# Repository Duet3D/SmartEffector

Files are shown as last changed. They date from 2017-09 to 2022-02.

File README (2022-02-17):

The Duet3d Smart Effector design files repository.

See https://www.duet3d.com/DeltaSmartEffector for more information and to purchase a smart effector.

Duet3d Delta Smart Effector
Design by Tony Lock and David Crocker
LICENSE: see the LICENSE file in the repository
Documentation: https://docs.duet3d.com/Duet3D_hardware/Accessories/Smart_Effector
Discussion: https://www.duet3d.com/forum/

Developed in KiCAD: http://www.kicad-pcb.org/display/KICAD/KiCad+EDA+Software+Suite

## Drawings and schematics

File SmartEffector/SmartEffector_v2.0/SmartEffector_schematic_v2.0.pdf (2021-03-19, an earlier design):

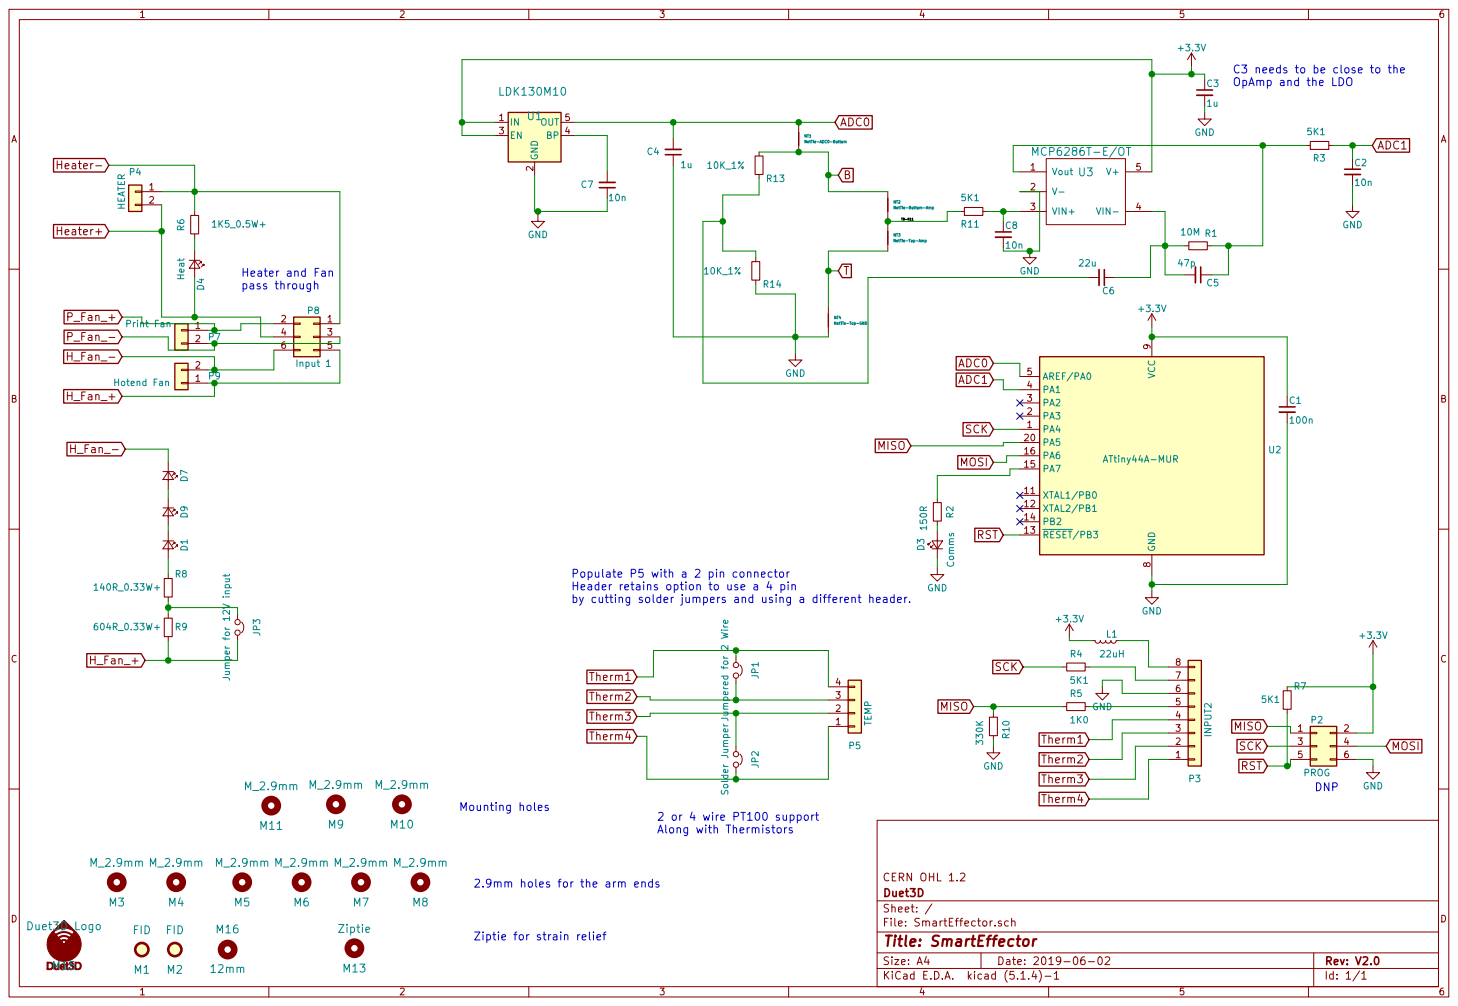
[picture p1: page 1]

C3 needs to be close to the
OpAmp and the LDO

NT3 NetTie-Top-Amp NT2NetTie-Bottom-Amp NT1NetTie-ADC0-Bottom

Populate P5 with a 2 pin connector
Header retains option to use a 4 pin
by cutting solder jumpers and using a different header.

CERN OHL 1.2
Id: 1/1 Title: SmartEffector File: SmartEffector.sch Sheet: / Duet3D

Ziptie for strain relief 2.9mm holes for the arm ends

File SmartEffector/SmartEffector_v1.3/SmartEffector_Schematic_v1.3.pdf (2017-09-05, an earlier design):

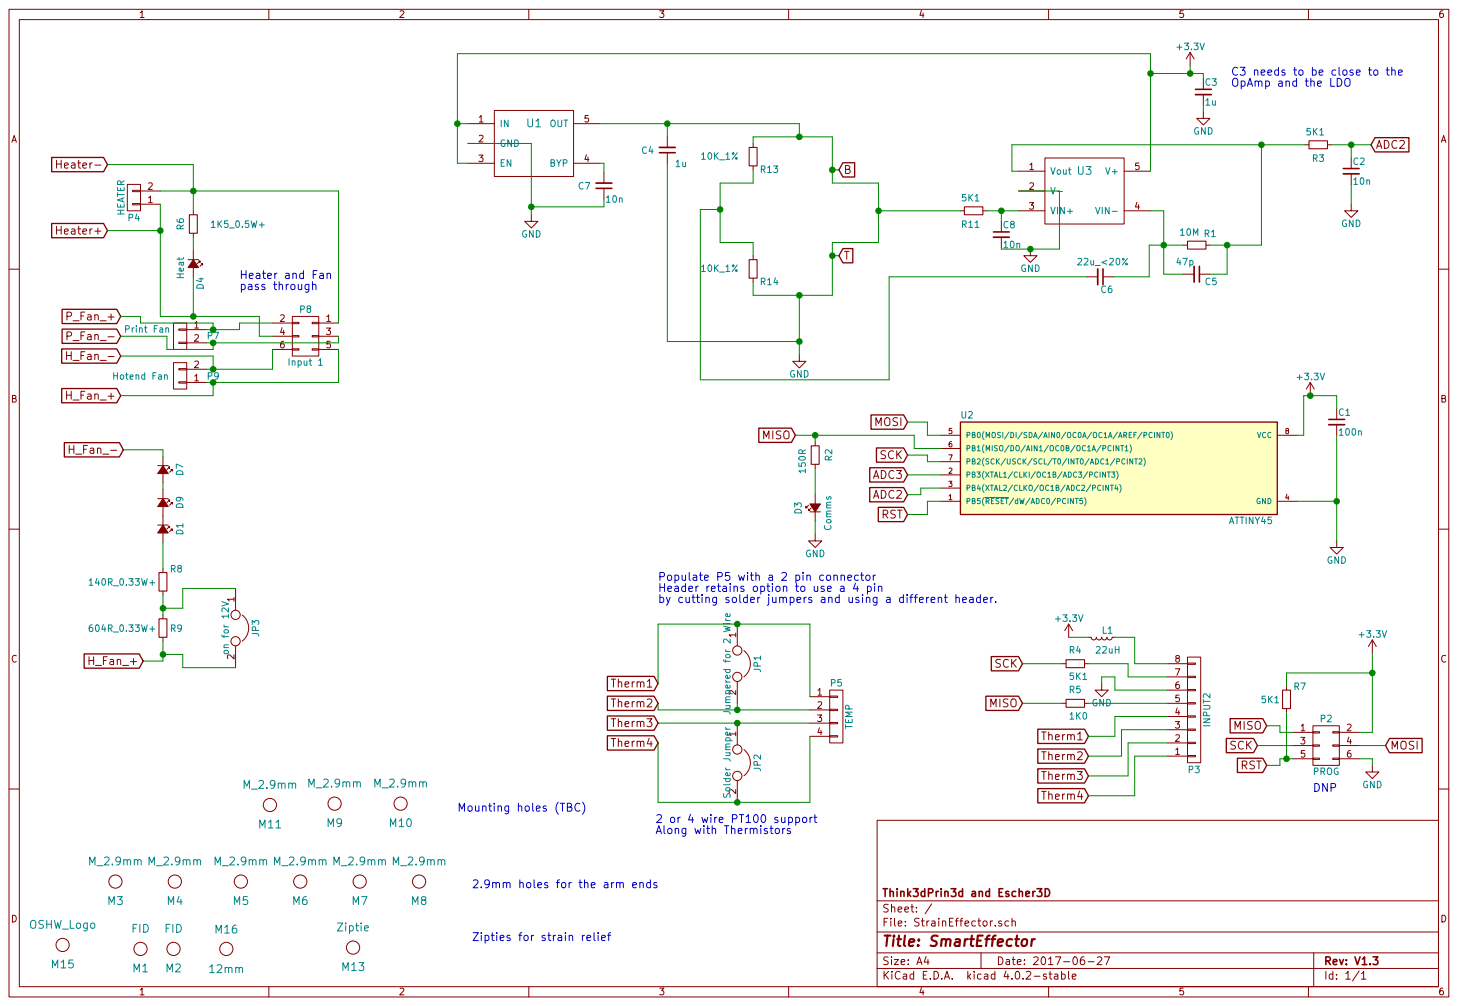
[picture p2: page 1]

1 2 JP3 on for 12V Heater+ Heater- C3

OpAmp and the LDO

1 2 JP2 Solder Jumper 1 2 JP1 Jumpered for 2 Wire C8

Populate P5 with a 2 pin connector
Header retains option to use a 4 pin

by cutting solder jumpers and using a different header. Therm4 Therm3

Id: 1/1 Title: SmartEffector File: StrainEffector.sch Sheet: / Think3dPrin3d and Escher3D

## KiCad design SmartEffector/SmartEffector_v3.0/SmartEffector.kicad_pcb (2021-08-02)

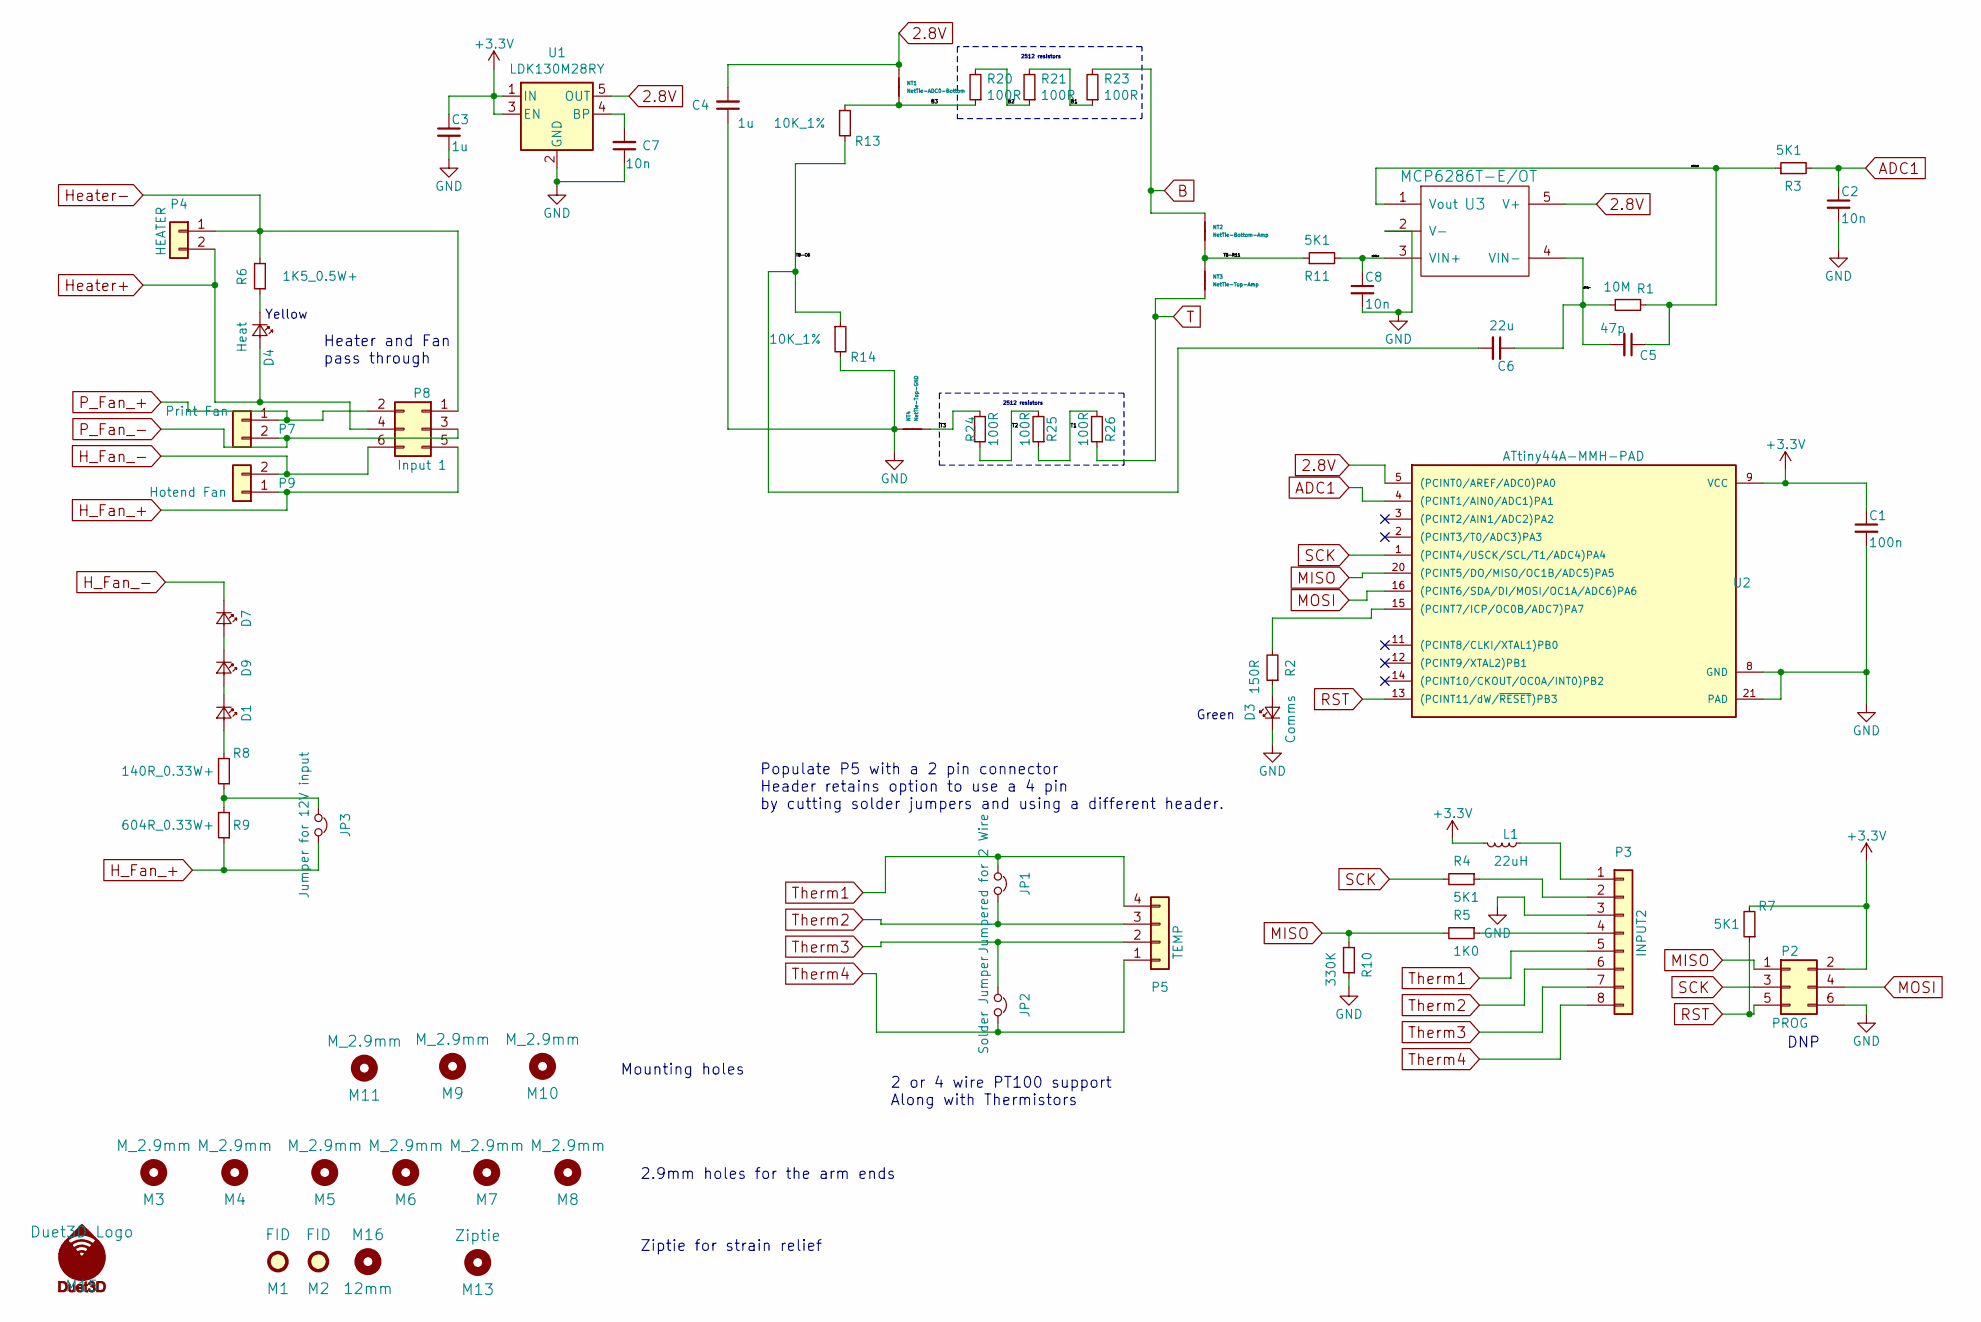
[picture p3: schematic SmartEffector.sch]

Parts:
C1: 100n; C_0402_1005Metric_Wbry; Part Number CL05A104KA5NNNC
C2, C7, C8: 10n; C_0402_1005Metric_Wbry; Part Number CL05B103KB5NNNC
C3, C4: 1u; C_0603_1608Metric_Wbry; Part Number CL10B105MO8NNWC
C5: 47p; C_0603_1608Metric_Wbry; Part Number 06035C470JAT2A
C6: 22u; C_0805_2012Metric; Part Number GRM21BR61A226ME51L or similar
D1, D7, D9: illum; LED_Wurth-158302260; Part Number 158302260
D3: Comms; LED_1206_bottom_entry_156120VS75000; Part Number 156120VS75000
D4: Heat; LED_1206_bottom_entry_156120VS75000; Part Number 156120YS75000
JP1: Jumpered for 2 Wire; SJ_Bridged; Part Number Virtual component DNP
JP2: Solder Jumper; SJ_Bridged; Part Number Virtual component DNP
JP3: Jumper for 12V input; JUMPER
L1: 22uH; L_0805_2012Metric; Part Number MLZ2012M220WT000
M1, M2: FID; Fiducial_1mm_Dia_2.54mm_Outer_CopperTop; Part Number Virtual component DNP
M3, M4, M5, M6, M7, M8, M9, M10, M11: M_2.9mm; MountingHole_2.9mm; Part Number Virtual component DNP
M13: Ziptie; Ziptie_small; Part Number Virtual component DNP
M15: Duet3D Logo; LOGO_Duet3d_CU_Mask; Part Number Virtual component DNP
M16: 12mm; 12mmHole; Part Number Virtual component DNP
NT1: NetTie-ADC0-Bottom; NetTie-2_SMD_Pad0.25mm; Part Number Virtual component DNP
NT2: NetTie-Bottom-Amp; NetTie-2_SMD_Pad0.5mm; Part Number Virtual component DNP
NT3: NetTie-Top-Amp; NetTie-2_SMD_Pad0.5mm; Part Number Virtual component DNP
NT4: NetTie-Top-GND; NetTie-2_SMD_Pad0.5mm; Part Number Virtual component DNP
P2: PROG; Test_Point_2x3; Part Number Virtual component DNP
P3: INPUT2; Molex_KK-254_AE-6410-08A_1x08_P2.54mm_Vertical
P4: HEATER; 3.5MM_2X1
P5: TEMP; Microfit_01x02or04_43650-0227
P7: Print Fan; Wurth_61900211121-1x02_P2.54mm_Vertical-(Molex_KK-254_AE-64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
P8: Input 1; Microfit_02x03
P9: Hotend Fan; Microfit_01x02_43650-0227
R1: 10M; R_0603_1608Metric_Wbry; Part Number RMCF0603JG10M0
R2: 150R; R_0402_1005Metric_Wbry; Part Number RC0402FR-07150RL
R3, R4, R7, R11: 5K1; R_0402_1005Metric_Wbry; Part Number RMCF0402FT5K10
R5: 1K0; R_0402_1005Metric_Wbry; Part Number CR0402-FX-1001GLF
R6: 1K5_0.5W+; R_1206; Part Number CRGH1206F1K5
R8: 140R_0.33W+; R_0805_extended_pads; Part Number ERJP06F1400V
R9: 604R_0.33W+; R_1206_3216Metric; Part Number RNCP1206FTD604R
R10: 330K; R_0402_1005Metric_Wbry; Part Number RMCF0402FT330K
R13, R14: 10K_1%; R_0402_1005Metric_Wbry; Part Number RK73H1ETTP1002F
R20, R21, R23, R24, R25, R26: 100R; R_2512_6332Metric; Part Number CRCW2512100RFKEG
U1: LDK130M28RY; SOT-23-5L; Part Number LDK130M28RY with LDK130M29R as an alter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
U2: ATtiny44A-MMH-PAD; QFN-20-1EP_4x4mm_Pitch0.5mm; Part Number ATtiny44A-MUR
U3: MCP6286T-E/OT; SOT-23-5L; Part Number OPA377AIDBVR preferred, possible to rev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

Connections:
2.8V: C4.2, NT1.1, U1.5 (OUT), U2.5 ((PCINT0/AREF/ADC0)PA0), U3.5 (V+)
+3V3: C1.1, C3.1, L1.2, P2.2, R7.2, U1.1 (IN), U1.3 (EN), U2.9 (VCC)
/B1: R21.2, R23.1
/B2: R20.2, R21.1
/B3: NT1.2, R13.1, R20.1
/T1: R25.1, R26.2
/T2: R24.2, R25.2
/T3: NT4.2, R24.1
/TB-C6: C6.2, R13.2, R14.1
/TB-R11: NT2.2, NT3.1, R11.1
/u3Vout: C5.1, R1.2, R3.1, U3.1 (Vout)
/u3vin+: C8.1, R11.2, U3.3 (VIN+)
/u3vin-: C5.2, C6.1, R1.1, U3.4 (VIN-)
ADC1: C2.1, R3.2, U2.4 ((PCINT1/AIN0/ADC1)PA1)
B: NT2.1, R23.2
GND: C1.2, C2.2, C3.2, C4.1, C7.1, C8.2, D3.1 (K), NT4.1, P2.6, P3.3, R10.1, R14.2, U1.2 (GND), U2.8 (GND), U2.21 (PAD), U3.2 (V-)
H_Fan_+: JP3.2, P8.5, P9.1, R9.1
H_Fan_-: D7.1 (K), P8.6, P9.2
Heater+: D4.2 (A), P4.2, P8.4
Heater-: P4.1, P8.1, R6.2
MISO: P2.1, R5.2, R10.2, U2.20 ((PCINT5/DO/MISO/OC1B/ADC5)PA5)
MOSI: P2.4, U2.16 ((PCINT6/SDA/DI/MOSI/OC1A/ADC6)PA6)
unnamed: C7.2, U1.4 (BP)
unnamed: D1.1 (K), D9.2 (A)
unnamed: D1.2 (A), R8.2
unnamed: D3.2 (A), R2.1
unnamed: D4.1 (K), R6.1
unnamed: D7.2 (A), D9.1 (K)
unnamed: JP3.1, R8.1, R9.2
unnamed: L1.1, P3.1
unnamed: P3.2, R4.1
unnamed: P3.4, R5.1
unnamed: R2.2, U2.15 ((PCINT7/ICP/OC0B/ADC7)PA7)
P_Fan_+: P7.1, P8.2
P_Fan_-: P7.2, P8.3
RST: P2.5, R7.1, U2.13 ((PCINT11/dW/~RESET~)PB3)
SCK: P2.3, R4.2, U2.1 ((PCINT4/USCK/SCL/T1/ADC4)PA4)
T: NT3.2, R26.1
Therm1: JP1.1, P3.5, P5.4
Therm2: JP1.2, P3.6, P5.3
Therm3: JP2.1, P3.7, P5.2
Therm4: JP2.2, P3.8, P5.1

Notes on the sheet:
DNP
Heater and Fan pass through
2.9mm holes for the arm ends
Ziptie for strain relief
2 or 4 wire PT100 support Along with Thermistors
Populate P5 with a 2 pin connector Header retains option to use a 4 pin by cutting solder jumpers and using a different header.
Mounting holes
2512 resistors
Yellow
Green

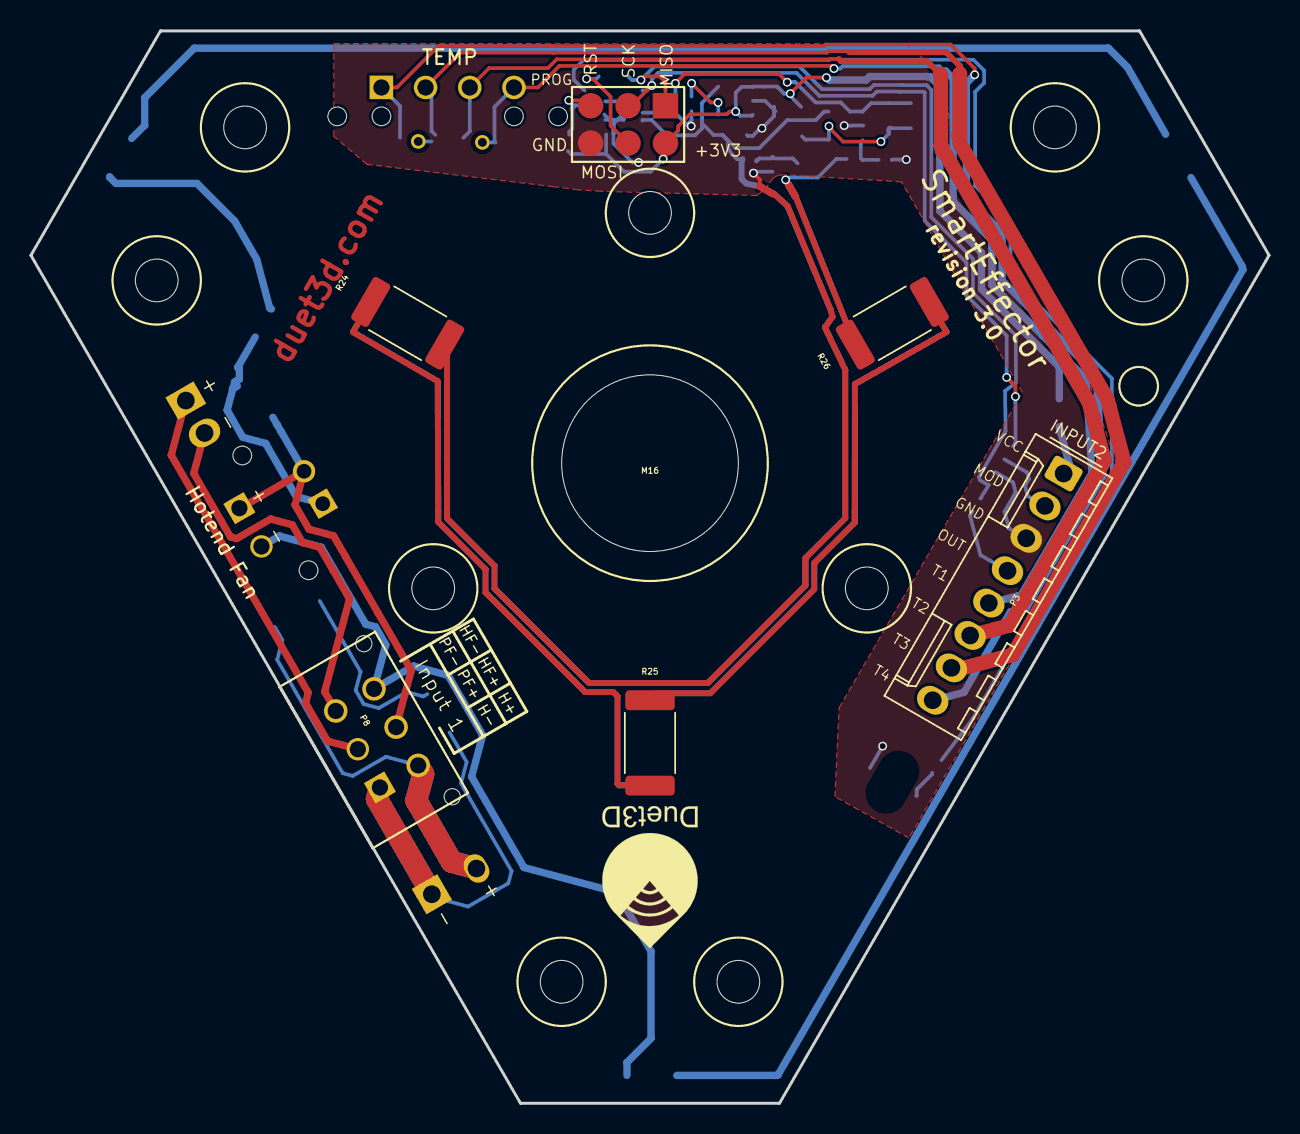
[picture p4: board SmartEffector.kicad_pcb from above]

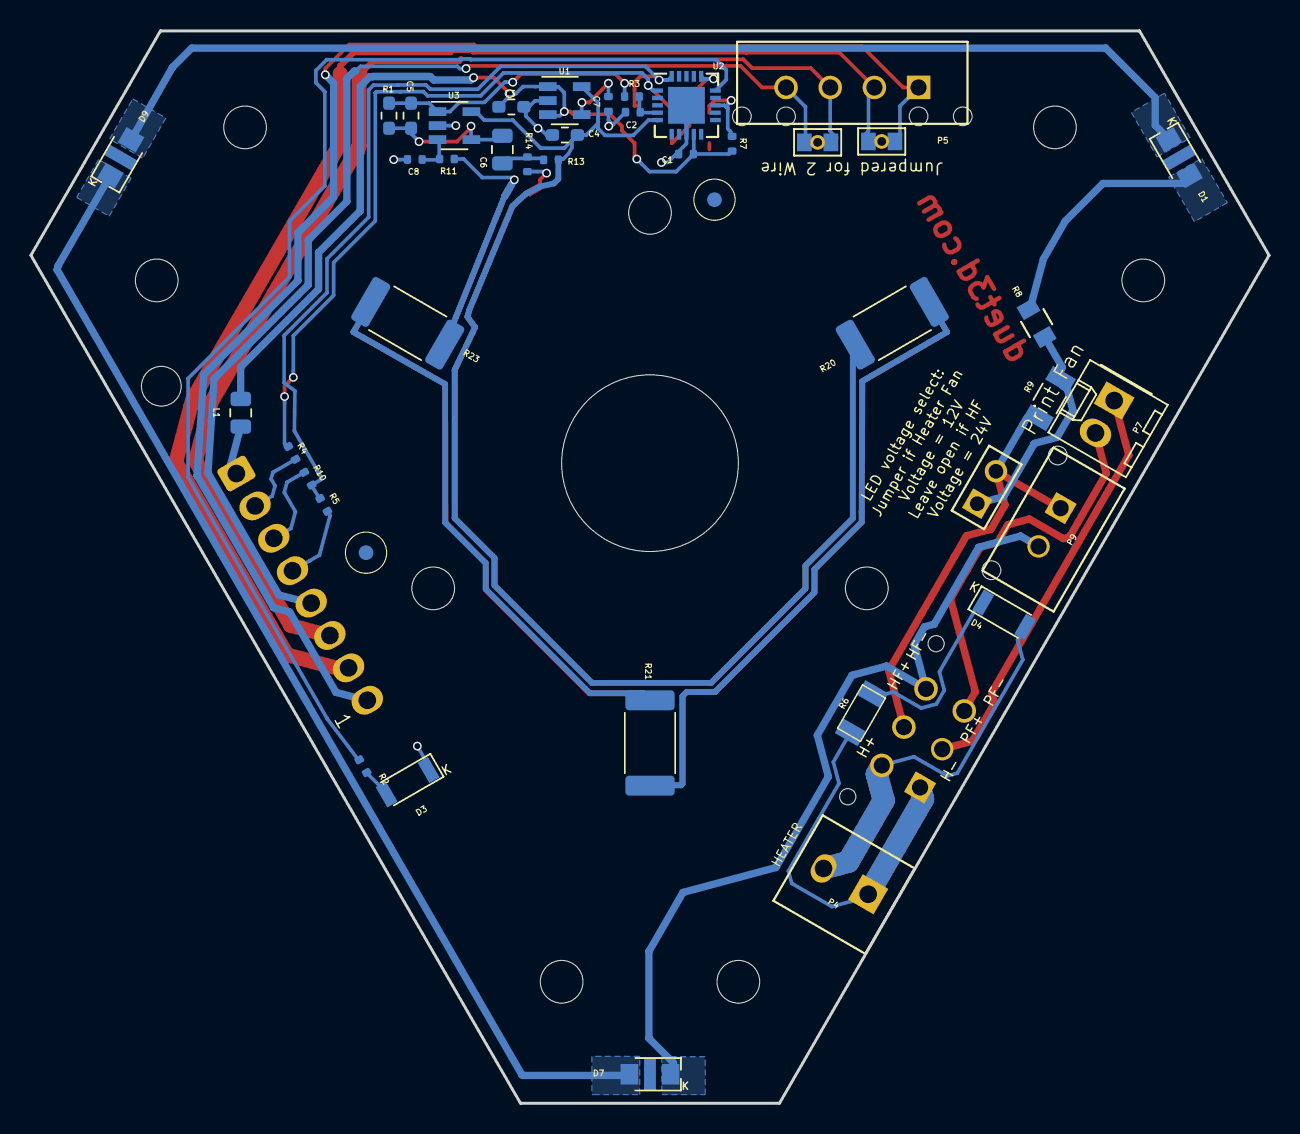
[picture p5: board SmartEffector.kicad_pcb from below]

Board: 2 copper layers, 84.1 x 72.8 mm, 64 parts (44 on the bottom side), 42 nets.

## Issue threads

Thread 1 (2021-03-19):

BOM error, ATtiny

oesvends, 2021-03-19:
Hi,
I manufactured a set of PCBs for the Smarteffector 2.0, and when mounting the ATtiny44-MMH, I see that the PCB layout is intended for the ATTiny44-MU (4x4mm package) and not the MMH-version (3.1x3.1) package.

The Schematic should be fixed, IMO.

Regards, and thanks.

T3P3, 2021-03-19:
latest commit (https://github.com/Duet3D/SmartEffector/commit/0d208e377e57fa8604e8f18ab95525f88173d331) resolves this, thanks for point it out.

Closed 2021-03-19.

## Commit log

2017-09-05 Smart Effector version 1.3
    Initial production model
    [SmartEffector.kicad_pcb, SmartEffector.sch]
2017-09-05 Carriage Adaptor for Delta Smart Effector
    [CarriageAdaptor.kicad_pcb, CarriageAdaptor.sch]
2019-06-02 SmartEffector 2.0 KiCAD source added
    [SmartEffector.kicad_pcb, SmartEffector.sch]
2021-03-19 Updated some schematic issues
    [SmartEffector.kicad_pcb, SmartEffector.sch]
2021-08-02 Smart Effector v3.0 source files and STEP
    [SmartEffector.kicad_pcb, SmartEffector.sch]
2025-01-20 v4.0 Schematic
